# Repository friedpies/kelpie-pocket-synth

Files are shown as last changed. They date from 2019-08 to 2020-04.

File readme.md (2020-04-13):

## KELPIE - a polyphonic pocket synth

kelpie
---
### About

The KELPIE is a digital polyphonic synthesizer powered by the SGTL5000 audio DAC and an ARM Cortex M4 microcontroller. For a description of the full project, please visit the [Hackaday Project Page](https://hackaday.io/project/166460-kelpie-synth-module-for-keyboard-controllers)

---
### Repository Details

This repo houses all mechanical, electrical, and software files relating to the project, as well as graphical assets and other additional files.

- Mechanical CAD (mCAD) files can be found and viewed [here](https://a360.co/2Hpqyr5) via Fusion 360's online viewer. They can be downloaded directly in whatever format you need (including STLs for 3D printing). The link provided here directly reflects the most current progress and is kept up-to-date in real time.
- Electronics CAD ([Autodesk Eagle](https://www.autodesk.com/products/eagle/free-download)) files and schematics can be found [here](https://github.com/friedpies/kelpie-pocket-synth/tree/master/hardware/electronics). The parts library and full BOM can be exported from the schematic. This is the most up-to-date BOM.
- Firmware files, written in Arduino/C++ using [PlatformIO](https://platformio.org/) can be found [here](https://github.com/friedpies/kelpie-pocket-synth/tree/master/firmware)

### Audio Design

The synthesizer block diagram is shown below and was designed using the [Teensy Audio Design Tool](https://www.pjrc.com/teensy/gui/index.html)

BlockDiagram

---

### About the Device / How to Use


The KELPIE is a subtractive synthesizer that follows the standard 2 oscillator model. For those who have never used a subtractive synth before, there are plenty of resources online, I would recommend [this series of videos](https://www.youtube.com/watch?v=-1iK6drewCE) which do a great job of explaning and demonstrating the basics.

Some unique features of the KELPIE that are different and worth pointing out are:

 #### Oscillators
 - Each oscillator can only generate either a `pulse` waveform or `sawtooth` (both these waveforms are harmonically rich compared to triangle/sine waves, and can easily emulate other waves through filtering)
 - The `Pulse Width Modulation knob` (PWM) can only be heard if one (or both) of the waveforms are switched to a pulse waveform. This knob can be thought of as a "global" PWM
 - The `noise` knob is more of a noise "presence". At `0%`, oscillators 1 & 2 will dominate the output. Whereas at `100%`, the noise will completely dominate the output. At `50%` there will be an equal gain of Oscillators 1 & 2 and Noise.
 - `Coarse` refers to the relative tuning of Oscillator 2 to Oscillator 1. At `0%`, Oscillator 2 is tuned 1 octave below Oscillator 1, at `100%`, Oscillator 2 is tuned 1 octave above. Around `50%`, the knob is less sensitive in order to achieve less dramatic detuning.

#### Envelopes
  - The envelope knobs are responsible for both `amp` and `filter` envelopes. To switch between `amp` and `filter`, active the `shift` button. In future revisions, more features may be attached to the `shift` button.

#### Filter
  - Both filter `freq` and `Q` or (resonance) behave as expected in a traditional subtractive synthesizer. However, `depth` can be explained as the filter's impact or octave range. This effect is manifested in both the `LFO`'s `filter` parameter, as well as the `filter enevelope`'s effect on the overall sound.

#### LFO
  - The KELPIE has a single `LFO` or `low frequency oscillator` which is mapped to both the `filter`'s frequency as well as the overall `master gain`. The `rate` describes the frequency of oscillation, whereas the `filter` and `amp` parameters describe the `LFO`'s effect on those destinations.
  - Currently, the `LFO rate` is also mapped to the `modulation` MIDI CC message, so a player can easily adjust this parameter directly from their MIDI control interface.

#### GLIDE
  - This feature has not yet been implemented, but will allow the user to change the overall portamento rate (sliding between notes in `mono` mode)

#### MIDI CC
  - The KELPIE accepts `MIDI CC` messages from `102 - 119` which allow adjustment of all the parameters on the device. Both the built-in knobs and external MIDI knobs can be used simultaneously.

---

### Acknowledgements

I utilized and referenced a couple of open source libraries + repos for this project, as well as some very useful tools:

- PJRC Audio Library and Audio Design Tool
- [Bounce](https://github.com/thomasfredericks/Bounce2) library by Thomas Fredericks
- [MIDI](https://github.com/FortySevenEffects/arduino_midi_library) library by Francois Best
- thewknd's [Teensy Reference Boards schematics](https://github.com/thewknd/teensy-boards/tree/master/Teensy%203.2%20reference%20board%20clone)
- [Note's and Volts](https://www.notesandvolts.com/2018/05/teensy-synth-part-1.html) tutorial videos on building a Teensy synth

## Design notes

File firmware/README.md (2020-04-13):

### KELPIE SYNTHESIZER
By Kenneth Marut
www.kennethmarut.com

A custom hardware synthesizer based off of the Teensy 3.2 development hardware. This repository houses all firmware code, built using the Arduino language in PlatformIO.

## Getting Started with PlatformIO

This project uses VSCode with the PlatformIO extension instead of the Arduino IDE. To get set up, follow the instructions below:

- Download and install [VSCode](https://code.visualstudio.com/download) for your operating system
- Open VSCode and add the PlatformIO IDE Extension (platformio.platformio-ide)
- After PlatformIO finishes installing, restart VSCode
- Open PlatformIO by clicking on the "Alien" icon on VSCode's left toolbar
- Click on the "Platforms" icon, then search for the "Teensy" platform and install the latest version
- In the PIO Home window, select `Open Project` and navigate to `/kelpie-pocket-synth/firmware`
- Once the directory has been opened, click on the Alien PlatformIO icon on the left toolbar, and then select `Build` to compile the firmware
- Ensure the project has been successfully compiled, then connect your Kelpie/Teensy 3.2 via USB and select `Upload`
- After recompiling, the Teensy Loader should open and follow the familiar steps to flash the firmware to your device

The device firmware is written in C++ using the Arduino framework. The main entrypoint is `/src/main.cpp`. 
Custom libraries and classes can be found within the `/lib` directory. This is where most of the code lives.

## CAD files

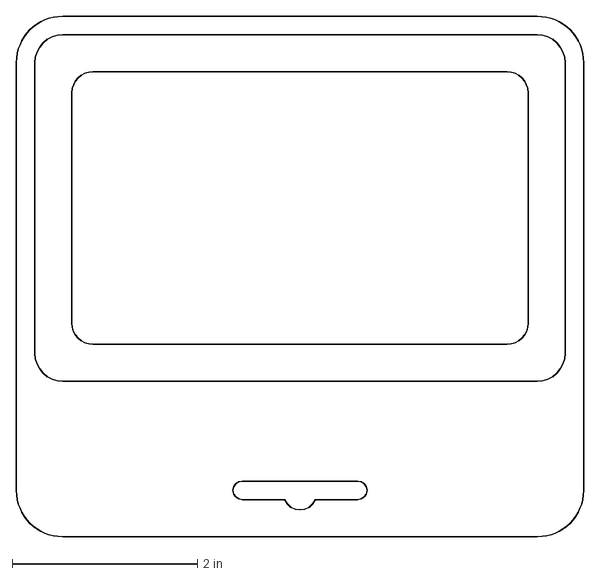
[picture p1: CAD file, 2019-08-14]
graphics/PACKAGING/OUTLINE.dxf
6.13 x 5.62 in

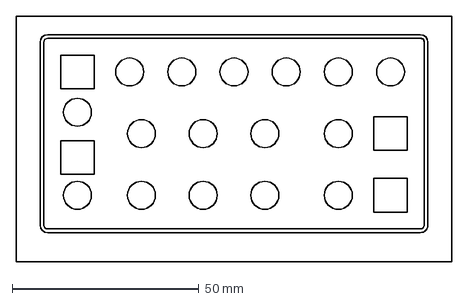
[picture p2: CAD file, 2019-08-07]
graphics/top_dxf.dxf
116.6 x 65.8 mm

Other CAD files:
hardware/enclosure/STLs/ENCLOSURE_TOP_TEXT_TEST.stl
hardware/enclosure/STLs/ENCLOSURE_BOTTOM.stl
hardware/enclosure/STLs/FDM-KNOB.stl
hardware/enclosure/STLs/KNOB.stl
hardware/enclosure/STLs/RING.stl
hardware/enclosure/STLs/KNOB_6MM.stl
hardware/enclosure/STLs/ENCLOSURE_TOP.stl

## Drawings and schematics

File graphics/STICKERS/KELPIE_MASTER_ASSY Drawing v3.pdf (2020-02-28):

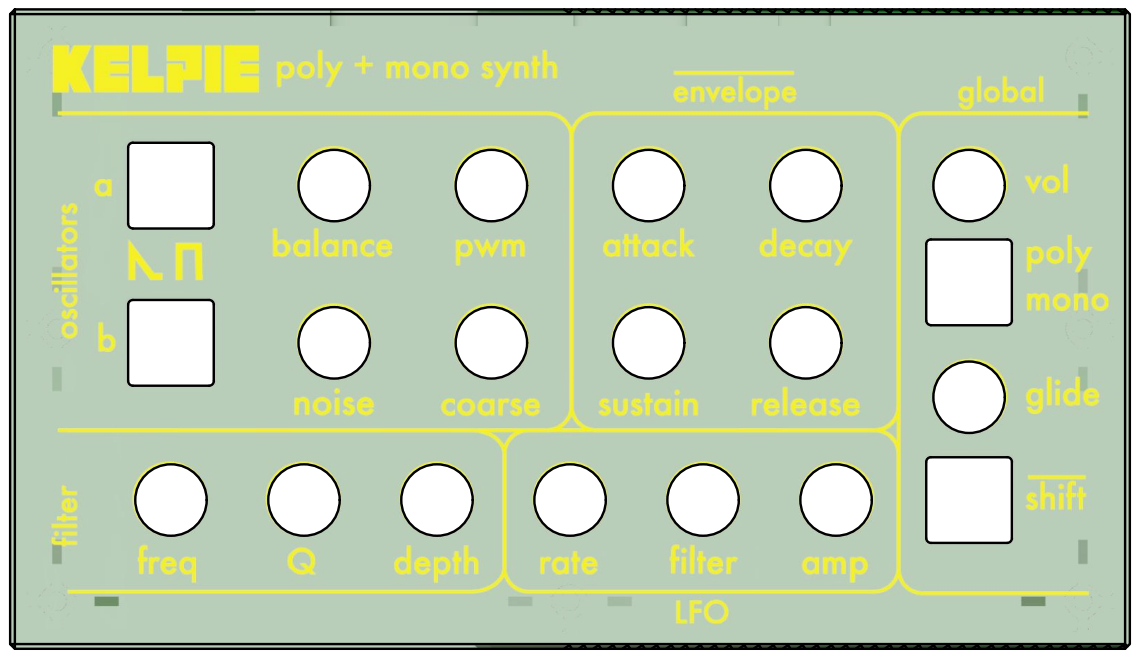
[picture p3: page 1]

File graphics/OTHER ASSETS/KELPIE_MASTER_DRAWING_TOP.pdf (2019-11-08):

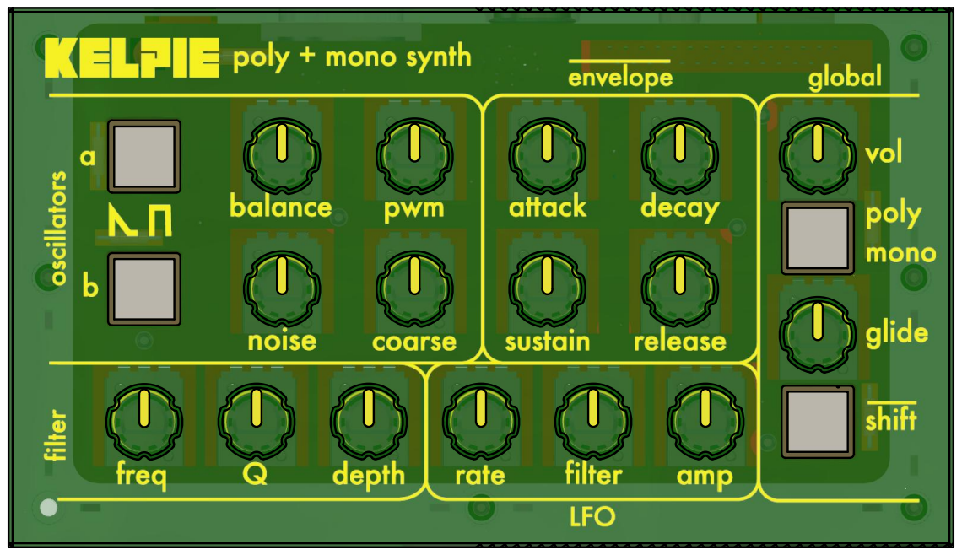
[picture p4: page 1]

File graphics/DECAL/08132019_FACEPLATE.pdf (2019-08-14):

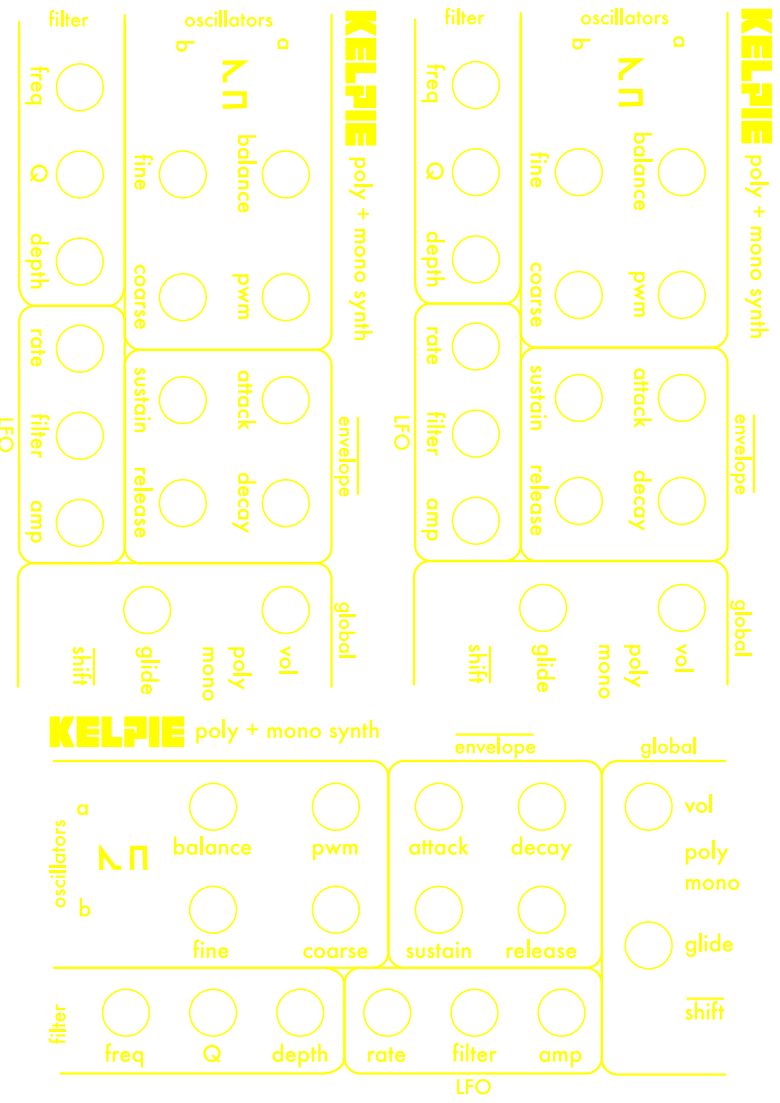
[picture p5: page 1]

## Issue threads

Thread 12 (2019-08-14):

feature: implement velocity sensitivity

friedpies, 2019-08-14:
- update synth engine to add amp to all voices

- map velocity to amp

friedpies, 2019-08-14:
Fixed!

Closed 2019-08-14.

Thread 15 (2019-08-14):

electronics: replace 30pin connector with ZIF connector

friedpies, 2019-08-14:
The current connector is expensive and impractical. Want to go with something cheaper and easier to install

Closed 2019-08-31.

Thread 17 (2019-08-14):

electronics: expose copper pads on potentiometer mounting holes

friedpies, 2019-08-14:
The mounting holes for the potentiometers are covered with silkscreen making it impossible to solder the mounting holes for the pots

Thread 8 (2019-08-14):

firmware: Implement Pitch Bend MIDI message

friedpies, 2019-08-14:
- Add a case for a midi pitch bend message
- adjust frequency when note is sounding in real time

friedpies, 2019-08-14:
DONE!

Closed 2019-08-14.

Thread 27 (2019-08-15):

firmware: device crashes when hitting 10-12 keys at once

friedpies, 2019-08-15:
seems to be a new issue

friedpies, 2019-08-19:
Temporary fix is to reduce number of voices to 6 at a time

Closed 2019-08-19.

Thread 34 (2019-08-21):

firmware: clear voices function

friedpies, 2019-08-21:
implement a function to clear all voices before switching from mono to poly, there is some residual data/noise that seems to carry over

Closed 2019-08-21.

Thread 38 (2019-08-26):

electronics: cut notch from upper PCB for MIDI connector

friedpies, 2019-08-26:
Wish I had thought of this earlier, likely can save a ton of space by moving some components around or notching out a chunk of the upper pcb to make space for MIDI connector... oh well

Closed 2019-08-31.

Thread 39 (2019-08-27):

electronics: replace all SMD components on upper PCB with thru hole

friedpies, 2019-08-27:
Figure that all pots and switches are thru-hole anyway, no reason to have two different types of components. This board is likely hand-assembled anyway.

friedpies, 2019-08-31:
Done

Closed 2019-08-31.

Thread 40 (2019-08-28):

hardware: fix ribs in lower enclosure

friedpies, 2019-08-28:
some ribs are interfering with lower half of enclosure

friedpies, 2019-08-31:
New design

Closed 2019-08-31.

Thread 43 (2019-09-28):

hardware: Possible incorrect component in Logic BOM

jawsper, 2019-09-28:
I saw in the BOM of the Logic board that you're referring to the AP7317-33SR voltage regulator for the SGTL5000 audio chip. I think this may be an error, since the audio chip needs a 1.1V - 2.0V level on that pin and this is a 3.3V regulator. The official Audio Shield uses the AP7317-18SR (package code SD) which does supply the correct level.

I hope this is only an error in the BOM, because it may very well break the audio chip.

friedpies, 2019-09-28:
hey @jawsper, I believe you are correct! Thank you for catching this error. I'll update the Eagle files and BOM. I really appreciate it. Also will swap those parts out on my boards. Luckily haven't broken anything yet!!

Closed 2019-09-28.

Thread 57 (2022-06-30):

The main repository's hardware PCB file is corrupted

denjhang, 2022-06-30:
I found a whole bunch of 1kb files, there must be something wrong.

berryelectronics, 2023-11-07:
had the same problem when downloading the repo as a zip, but works without a problem when using git clone

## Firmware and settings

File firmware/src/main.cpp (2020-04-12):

// MAIN CODE FOR KELPIE SYNTHESIZER
// WRITTEN BY KENNETH MARUT (WWW.KENNETHMARUT.COM)
// THIS PROJECT CAN BE FOLLOWED HERE: https://hackaday.io/project/166460-kelpie-synth-module-for-keyboard-controllers

#include <Arduino.h>
#include <MIDI.h>
#include <Audio.h>
#include <audioConnections.h>
#include <KelpieHelpers.h>
#include <KelpieIO.h>


elapsedMillis fps;
KelpieIO kelpieIO(true);
MIDI_CREATE_INSTANCE(HardwareSerial, Serial1, MIDI);

boolean prevButtonsState[4] = {false, false, false, false}; // initial state on boot
boolean *buttonsState;
byte changedKnobIndex;
byte changedButtonIndex;

SynthVoice VOICE_1 = {0, 0.0, 0, false, V1_A, V1_B, V1_N, V1_MIX, V1_AMP, V1_ENV, V1_FILT_ENV, V1_FILT};
SynthVoice VOICE_2 = {0, 0.0, 0, false, V2_A, V2_B, V2_N, V2_MIX, V2_AMP, V2_ENV, V2_FILT_ENV, V2_FILT};
SynthVoice VOICE_3 = {0, 0.0, 0, false, V3_A, V3_B, V3_N, V3_MIX, V3_AMP, V3_ENV, V3_FILT_ENV, V3_FILT};
SynthVoice VOICE_4 = {0, 0.0, 0, false, V4_A, V4_B, V4_N, V4_MIX, V4_AMP, V4_ENV, V4_FILT_ENV, V4_FILT};
SynthVoice VOICE_5 = {0, 0.0, 0, false, V5_A, V5_B, V5_N, V5_MIX, V5_AMP, V5_ENV, V5_FILT_ENV, V5_FILT};
SynthVoice VOICE_6 = {0, 0.0, 0, false, V6_A, V6_B, V6_N, V6_MIX, V6_AMP, V6_ENV, V6_FILT_ENV, V6_FILT};
SynthVoice VOICE_7 = {0, 0.0, 0, false, V7_A, V7_B, V7_N, V7_MIX, V7_AMP, V7_ENV, V7_FILT_ENV, V7_FILT};
SynthVoice VOICE_8 = {0, 0.0, 0, false, V8_A, V8_B, V8_N, V8_MIX, V8_AMP, V8_ENV, V8_FILT_ENV, V8_FILT};

const byte numPolyVoices = 8; // 
SynthVoice polyVoices[numPolyVoices] = {
    VOICE_1,
    VOICE_2,
    VOICE_3,
    VOICE_4,
    VOICE_5,
    VOICE_6,
    VOICE_7,
    VOICE_8};

const byte MONOBUFFERSIZE = 8; // how many voices we allow to be stored in the MONO buffer
byte monoBuffer[MONOBUFFERSIZE];

SynthState globalState = {
    // default synth state on startup
    WAVEFORM_SAWTOOTH, // WAVEFORM1
    WAVEFORM_SAWTOOTH, // WAVEFORM2
    false,             // IS_POLY
    false,             // shift
    1.0,               // OSC1_VOL
    1.0,               // OSC2_VOL
    1.0,               // NOISE_VOL
    0.0,               // OSC_CONSTANT
    0.5,               // PWM
    1.0,               // DETUNE
    1.0,               // PITCH_BEND
    0.0,               // LFO_FREQ
    0.0,               // LFO_FILTER_GAIN
    0.0,               // LFO_AMP_GAIN
    0.0,               // AMP_ATTACK
    0.0,               // AMP_DECAY
    1.0,               // AMP_SUSTAIN
    500,               // AMP_RELEASE ms
    0.0,               // FILTER_ATTACK
    0.0,               // FILTER_DECAY
    1.0,               // FILTER_SUSTAIN
    500,               // FILTER_RELEASE
    10000,             // FILTER_FREQ
    1.1,               // FILTER_Q
    1.0,               // FILTER_OCTAVE
    0.5,               // MASTER_VOL
    1.0,               // POLY_GAIN_MULTIPLIER
    0.9,               // PREFILTER_GAIN
    0,                 // PREV_NOTE
    0                  // CURRENT NOTE
};

void handleMidiEvent(byte channelByte, byte controlByte, byte valueByte)
{
  byte messageType = MIDI.getType();
  byte note = MIDI.getData1();
  byte velocity = MIDI.getData2();
  int pitch = 0; // initialize to zero, only applies in pitch bend case
  float pitchBend = 0.00;
  switch (messageType)
  {
  case midi::NoteOn:
    kelpieIO.blinkMidiLED(true);
    if (note > 23 && note < 108)
    {
      LFO.phase(0); // retrigger LFO on keypress
      float noteGain = pow(float(velocity) * DIV127, VELOCITY_CURVE);

      if (globalState.IS_POLY == true) // depending on mode send to buffer
      {
        keyBuffPoly(note, noteGain, true);
      }
      else
      {
        keyBuffMono(note, noteGain, true);
      }
    }
    break;

  case midi::NoteOff:
    kelpieIO.blinkMidiLED(false);
    if (note > 23 && note < 108)
    {
      if (globalState.IS_POLY == true) // depending on mode send to buffer
      {
        keyBuffPoly(note, velocity, false);
      }
      else
      {
        keyBuffMono(note, velocity, false);
      }
    }
    break;

  case midi::PitchBend:
    pitch = velocity * 256 + note; // this converts 8 bit values into a 16 bit value for precise pitch control
    pitchBend = map(double(pitch), 0, 32767, -2, 2);
    globalState.PITCH_BEND = pow(2, pitchBend / 12);
    for (byte i = 0; i < numPolyVoices; i++)
    {
      float currentFreq = polyVoices[i].noteFreq;
      polyVoices[i].waveformA.frequency(currentFreq * globalState.PITCH_BEND);
      polyVoices[i].waveformB.frequency(currentFreq * globalState.PITCH_BEND * globalState.DETUNE);
    }
    break;

  case midi::ControlChange:
    byte ccNum = note; // redefining for clarity
    byte value = velocity;
    float normalizedKnobVal = (value * DIV127);
    switch (ccNum) {
      case 1: // MODULATION WHEEL
        globalState.LFO_FREQ = normalizedKnobVal * LFO_FREQ_MAX;
        LFO.frequency(globalState.LFO_FREQ);
      break;
      case 5: // GLIDE
      break;
      case 7: // MASTER VOLUME
        globalState.MASTER_VOL = normalizedKnobVal * MAX_MASTER_GAIN;
        MASTER_GAIN.gain(globalState.MASTER_VOL * globalState.POLY_GAIN_MULTIPLIER);
      break;
      case 8: // OSC BALANCE
        globalState.OSC1_VOL = normalizedKnobVal;
        globalState.OSC2_VOL = 1 - (normalizedKnobVal);
        globalState.OSC_CONSTANT = calculateOscConstant(globalState.OSC1_VOL, globalState.OSC2_VOL, globalState.NOISE_VOL);
        setWaveformLevels(globalState.OSC1_VOL, globalState.OSC2_VOL, globalState.NOISE_VOL, globalState.OSC_CONSTANT);
      break;
      case 102: // OSCILLATOR PWM
        globalState.PWM = 0.1 + 0.4 * (1 - normalizedKnobVal);
        for (byte i = 0; i < numPolyVoices; i++)
        {
          polyVoices[i].waveformA.pulseWidth(globalState.PWM);
          polyVoices[i].waveformB.pulseWidth(globalState.PWM);
        }
      break;
      case 103: // NOISE VOLUME
        globalState.NOISE_VOL = normalizedKnobVal;
        globalState.OSC_CONSTANT = calculateOscConstant(globalState.OSC1_VOL, globalState.OSC2_VOL, globalState.NOISE_VOL);
        setWaveformLevels(globalState.OSC1_VOL, globalState.OSC2_VOL, globalState.NOISE_VOL, globalState.OSC_CONSTANT);
      break;
      case 104: // OSC DETUNE
        globalState.DETUNE = calculateDetuneValue(normalizedKnobVal);
        for (byte i = 0; i < numPolyVoices; i++)
        {
          polyVoices[i].waveformB.frequency(polyVoices[i].noteFreq * globalState.DETUNE * globalState.PITCH_BEND);
        }
      break;
      case 105: // FILTER FREQUENCY
        globalState.FILTER_FREQ = FILTER_CUTOFF_MAX * pow(normalizedKnobVal, 3);
        for (byte i = 0; i < numPolyVoices; i++)
        {
          polyVoices[i].filter.frequency(globalState.FILTER_FREQ);
        }
      break;
      case 106: // FILTER RESONANCE
        globalState.FILTER_Q = (FILTER_Q_MAX * normalizedKnobVal) + 1.1;
        globalState.PREFILTER_GAIN = 1 / globalState.FILTER_Q;
        for (byte i = 0; i < numPolyVoices; i++)
        {
          polyVoices[i].filter.resonance(globalState.FILTER_Q);
        }
      break;
      case 107: // FILTER DEPTH
        globalState.FILTER_OCTAVE = FILTER_OCTAVE_DEPTH * normalizedKnobVal;
        for (byte i = 0; i < numPolyVoices; i++)
        {
          polyVoices[i].filter.octaveControl(globalState.FILTER_OCTAVE);
        }
      break;
      case 108: // LFO RATE
        globalState.LFO_FREQ = LFO_FREQ_MAX * pow(normalizedKnobVal, 5);
        LFO.frequency(globalState.LFO_FREQ);
      break;
      case 109: // LFO DESTINATION FILTER
        globalState.LFO_FILTER_GAIN = (normalizedKnobVal);
        LFO_MIXER_FILTER.gain(1, globalState.LFO_FILTER_GAIN);
      break;
      case 110: // LFO DESTINATION AMP
        globalState.LFO_AMP_GAIN = (normalizedKnobVal);
        LFO_MIXER_AMP.gain(1, globalState.LFO_AMP_GAIN);
      break;
      case 111: // AMP ATTACK
      globalState.AMP_ATTACK = AMP_ATTACK_MAX * (normalizedKnobVal);
      if (globalState.AMP_ATTACK < 15) //
      {
        globalState.AMP_ATTACK = 0;
      }
      for (byte i = 0; i < numPolyVoices; i++)
      {
        polyVoices[i].ampEnv.attack(globalState.AMP_ATTACK);
      }
      break;
      case 112: // AMP DECAY
        globalState.AMP_DECAY = AMP_DECAY_MAX * normalizedKnobVal;
        for (byte i = 0; i < numPolyVoices; i++)
        {
          polyVoices[i].ampEnv.decay(globalState.AMP_DECAY);
        }
      break;
      case 113: // AMP SUSTAIN
        globalState.AMP_SUSTAIN = normalizedKnobVal;
        for (byte i = 0; i < numPolyVoices; i++)
        {
          polyVoices[i].ampEnv.sustain(globalState.AMP_SUSTAIN);
        }
      break;
      case 114: // AMP RELEASE
        globalState.AMP_RELEASE = AMP_RELEASE_MAX * normalizedKnobVal;
        for (byte i = 0; i < numPolyVoices; i++)
        {
          polyVoices[i].ampEnv.release(globalState.AMP_RELEASE);
        }
      break;
      case 115: // FILTER ATTACK
            globalState.FILTER_ATTACK = FILTER_ATTACK_MAX * normalizedKnobVal;
      if (globalState.FILTER_ATTACK < 15) //
      {
        globalState.FILTER_ATTACK = 0;
      }
      for (byte i = 0; i < numPolyVoices; i++)
      {
        polyVoices[i].filterEnv.attack(globalState.FILTER_ATTACK);
      }
      break;
      case 116: // FILTER DECAY
        globalState.FILTER_DECAY = FILTER_DECAY_MAX * normalizedKnobVal;
        for (byte i = 0; i < numPolyVoices; i++)
        {
          polyVoices[i].filterEnv.decay(globalState.FILTER_DECAY);
        }
      break;
      case 117: // FILTER SUSTAIN
        globalState.FILTER_SUSTAIN = normalizedKnobVal;
        for (byte i = 0; i < numPolyVoices; i++)
        {
          polyVoices[i].filterEnv.sustain(globalState.FILTER_SUSTAIN);
        }
      break;
      case 118: // FILTER RELEASE
        globalState.FILTER_RELEASE = FILTER_RELEASE_MAX * normalizedKnobVal;
        for (byte i = 0; i < numPolyVoices; i++)
        {
          polyVoices[i].filterEnv.release(globalState.FILTER_RELEASE);
        }
      break;
    }
    break;
  }
}

void setup()
{
  MIDI.begin();
  AudioMemory(80);
  sgtl5000_1.enable();
  sgtl5000_1.volume(globalState.MASTER_VOL);

  AudioNoInterrupts();
  for (byte i = 0; i < numPolyVoices; i++)
  {
    polyVoices[i].waveformA.begin(globalState.WAVEFORM1);
    polyVoices[i].waveformA.amplitude(0.33);
    polyVoices[i].waveformA.frequency(82.41);
    polyVoices[i].waveformA.pulseWidth(0.15);

    polyVoices[i].waveformB.begin(globalState.WAVEFORM2);
    polyVoices[i].waveformB.amplitude(0.33);
    polyVoices[i].waveformB.frequency(82.41);
    polyVoices[i].waveformB.pulseWidth(0.15);

    polyVoices[i].noise.amplitude(0.33);

    polyVoices[i].waveformMixer.gain(0, 1.0);
    polyVoices[i].waveformMixer.gain(1, 1.0);
    polyVoices[i].waveformMixer.gain(2, 1.0);

    polyVoices[i].waveformAmplifier.gain(0.0);

    polyVoices[i].ampEnv.attack(globalState.AMP_ATTACK);
    polyVoices[i].ampEnv.decay(globalState.AMP_DECAY);
    polyVoices[i].ampEnv.sustain(globalState.AMP_SUSTAIN);
    polyVoices[i].ampEnv.release(globalState.AMP_RELEASE);

    polyVoices[i].filter.frequency(globalState.FILTER_FREQ);
    polyVoices[i].filter.resonance(globalState.FILTER_Q);
    polyVoices[i].filter.octaveControl(2.0);
  }
  AudioInterrupts();

  DC_OFFSET.amplitude(1.0);
  LFO.amplitude(1.0);
  LFO.frequency(2.0);
  LFO.phase(90);

  LFO_MIXER_FILTER.gain(0, 1); // THIS IS THE AMP THAT ADJUSTS HOW MUCH OF THE LFO IS FED INTO THE FILTER
  LFO_MIXER_FILTER.gain(1, 0);

  for (byte i = 0; i < 4; i++)
  {
    V14_MIX.gain(i, 0.25);
    V58_MIX.gain(i, 0.25);
  }

  ALL_VOICE_MIX.gain(0, 0.5);
  ALL_VOICE_MIX.gain(1, 0.5);

  // READ AND INITIALIZE ALL KNOBS
  for (byte knobIndex = 0; knobIndex < 16; knobIndex++)
  {
    kelpieIO.setKnobOnStartup(knobIndex);
    handleKnobChange(kelpieIO.getKnob(knobIndex));
  }
  kelpieIO.bootupAnimation();
}

void loop()
{
  if (MIDI.read())
  {
    byte channel = MIDI.getChannel();
    byte controlType = MIDI.getData1();
    byte value = MIDI.getData2();
    handleMidiEvent(channel, controlType, value);
  }

  changedKnobIndex = kelpieIO.getIndexOfChangedKnob();
  if (changedKnobIndex > -1)
  {
    handleKnobChange(kelpieIO.getKnob(changedKnobIndex));
  }

  changedButtonIndex = kelpieIO.getIndexOfChangedButton();
  if (changedButtonIndex > -1)
  {
    handleButtonPress(kelpieIO.getButton(changedButtonIndex));
  }

  if (fps > 24)
  {
    if (PEAK.available())
    {
      fps = 0;
      int monoPeak = PEAK.read() * 100.0;
      Serial.print("|");
      for (int cnt = 0; cnt < 100; cnt++)
      if (cnt < monoPeak)
      {
        Serial.print(">");
      } else if (cnt >= monoPeak && cnt < 99)
      {
        Serial.print(" ");
      } else if (cnt > 99)
      {
        Serial.println("|");
      }
      Serial.print(monoPeak);
      Serial.println();
    }
  }
}

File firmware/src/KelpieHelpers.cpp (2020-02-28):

#include <KelpieHelpers.h>

void activateVoice(byte index, byte note, float frequency, float gain)
{
  polyVoices[index].note = note;
  polyVoices[index].noteFreq = frequency;
  polyVoices[index].waveformA.frequency(frequency * globalState.PITCH_BEND);
  polyVoices[index].waveformA.phase(0);
  polyVoices[index].waveformB.frequency(frequency * globalState.PITCH_BEND * globalState.DETUNE);
  polyVoices[index].waveformB.phase(0);
  polyVoices[index].waveformAmplifier.gain(gain * globalState.PREFILTER_GAIN);
  polyVoices[index].ampEnv.noteOn();
  polyVoices[index].filterEnv.noteOn();
}

void deactivateVoice(byte index)
{
  polyVoices[index].ampEnv.noteOff();
  polyVoices[index].filterEnv.noteOff();
  polyVoices[index].note = -1;
}

void playNoteMono(byte playMode, byte note, float noteGain)
{
  globalState.PREV_NOTE = globalState.CURRENT_NOTE;
  globalState.CURRENT_NOTE = note;
  if (globalState.CURRENT_NOTE == globalState.PREV_NOTE) {
    globalState.PREV_NOTE = 0; // this is a quick fix
    globalState.CURRENT_NOTE = 0;
  }
  float baseNoteFreq = noteFreqs[note];
  AudioNoInterrupts();
  switch (playMode) 
  {
  case PLAY_NOTE: // PLAYNOTE
    for (byte i = 0; i < numPolyVoices; i++)
    {
      activateVoice(i, note, baseNoteFreq, noteGain);
    }
    break;
  case UPDATE_NOTE: // UPDATE NOTE
    for (byte i = 0; i < numPolyVoices; i++)
    {
      polyVoices[i].note = note;
      polyVoices[i].noteFreq = baseNoteFreq;
      polyVoices[i].waveformA.frequency(baseNoteFreq);// * globalState.PITCH_BEND);
      polyVoices[i].waveformB.frequency(baseNoteFreq * globalState.PITCH_BEND * globalState.DETUNE);
    }
    break;
  case STOP_NOTE: // STOP NOTE
    for (byte i = 0; i < numPolyVoices; i++)
    {
      deactivateVoice(i);
    }
    break;
  }
  AudioInterrupts();
};

void bufferShift(byte indexToRemove, byte currentSizeOfBuffer)
{
  for (byte i = indexToRemove + 1; i < currentSizeOfBuffer; i++)
  {
    monoBuffer[i - 1] = monoBuffer[i];
  }
  monoBuffer[currentSizeOfBuffer - 1] = 0;
}

void keyBuffMono(byte note, float noteGain, boolean playNote)
{
  static byte currentNote = 0; // this might make more sense to start with -1 to keep indexing legible
  if (playNote)
  {
    if (currentNote == MONOBUFFERSIZE) // if we exceed buffer size, newest note goes on end, remove first note and SHIFT all notes down 1
    {
      bufferShift(0, currentNote);
      currentNote = MONOBUFFERSIZE - 1;
    }
    monoBuffer[currentNote] = note;
    playNoteMono(PLAY_NOTE, note, noteGain);
    currentNote++;
  }
  else // key is released
  {
    byte foundNoteIndex = MONOBUFFERSIZE; // default to index larger than buffer size
    for (byte i = 0; i <= (currentNote); i++)
    {

      if (note == monoBuffer[i])
      {
        foundNoteIndex = i;
        monoBuffer[i] = 0;
        // note has to be stopped
        bufferShift(foundNoteIndex, currentNote);
        currentNote--;
        if (currentNote == 0)
        {
          playNoteMono(STOP_NOTE, note, noteGain); 
        } else {
          playNoteMono(UPDATE_NOTE, monoBuffer[currentNote - 1], noteGain); // this is causing issues with the RELEASE phase of the AMP ENV
        }
      }
    }
  }
}

void keyBuffPoly(byte note, float noteGain, boolean playNote)
{
  if (playNote) // on keypress
  {
    float baseNoteFreq = noteFreqs[note];
    for (byte i = 0; i < numPolyVoices; i++)
    {
      if (polyVoices[i].ampEnv.isActive() == false)
      {
        activateVoice(i, note, baseNoteFreq, noteGain);
        break;
      }
    }
  }
  else // key released
  {
    for (byte i = 0; i < numPolyVoices; i++)
    {
      if (polyVoices[i].note == note)
      {
        deactivateVoice(i);
      }
    }
  }
}

void handleButtonPress(boolean *buttonsState)
{
  for (byte i = 0; i < 4; i++)
  {
    if (buttonsState[i] != prevButtonsState[i]) // which button changed?
    {
      prevButtonsState[i] = buttonsState[i];
      int pressedButton = i;
      boolean buttonState = boolean(buttonsState[i]);
      switch (pressedButton)
      {
      case OSC_1_BUTTON: // button 1 was pressed, toggle between waveforms
        if (buttonState == true)
        {
          globalState.WAVEFORM1 = WAVEFORM_PULSE;
        }
        else
        {
          globalState.WAVEFORM1 = WAVEFORM_SAWTOOTH;
        }
        for (byte i = 0; i < numPolyVoices; i++)
        {
          polyVoices[i].waveformA.begin(globalState.WAVEFORM1);
        }
        break;

      case OSC_2_BUTTON:
        if (buttonState == true)
        {
          globalState.WAVEFORM2 = WAVEFORM_PULSE;
        }
        else
        {
          globalState.WAVEFORM2 = WAVEFORM_SAWTOOTH;
        }
        for (byte i = 0; i < numPolyVoices; i++)
        {
          polyVoices[i].waveformB.begin(globalState.WAVEFORM2);
        }
        break;

      case POLY_MONO_BUTTON:
      // wipe out all notes playing just in case
        for (byte i = 0; i < numPolyVoices; i++) {
          deactivateVoice(i);
        }
        if (buttonState == true)
        {
          globalState.IS_POLY = true;
          globalState.POLY_GAIN_MULTIPLIER = POLY_MULTIPLIER;

        }
        else
        {
          globalState.IS_POLY = false;
          globalState.POLY_GAIN_MULTIPLIER = 1.0;
        }
        MASTER_GAIN.gain(globalState.MASTER_VOL * globalState.POLY_GAIN_MULTIPLIER);
        break;

      case SHIFT_BUTTON:

        if (buttonState == true)
        {
          globalState.SHIFT = true;
        }
        else
        {
          globalState.SHIFT = false;
        }
        break;

      default:
        break;
      }
    }
  }
}
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

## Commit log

2019-06-03 Boilerplate setup
    Initialized repo with simple "Hello World" program, tested MK20 on Kelpie board, working
2019-06-19 test pins and write pin defines
2019-06-20 test input switches, working
2019-06-28 restructuring folders
    [CONTROL.csv, MCU.csv, control.xlsx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]
2019-07-22 add digital read for buttons
2019-07-22 debouce pushbuttons and light corresponding LEDs
2019-08-04 rewrte buttons struct to match knobs
2019-08-05 implement env and filter
2019-08-05 implemented filter
2019-08-06 a couple quick fixes
    [main.cpp]
2019-08-07 add dxf
    [top_dxf.dxf]
2019-08-07 added filter envs to every voice
2019-08-13 quick fixes on gain and clipping
    [KelpieHelpers.cpp, main.cpp]
2019-08-14 pushing graphics
    [OUTLINE.dxf]
2019-08-14 implemented velocity sensitivity for poly synth
2019-08-14 added case for retrieving pitch bend control change and convert to 16 bit val
2019-08-14 implemented pitch bend
2019-08-15 broken: device crashes when 7 notes played simultaneously
    [KelpieHelpers.cpp, main.cpp]
2019-08-16 broken: removing voices until crashing stops
    [Kelpie.cpp, KelpieHelpers.cpp, main.cpp]
2019-08-20 mono working, need to replace all monovoices with polyvoices for consistency
    [KelpieHelpers.cpp]
2019-08-21 electronics updates
    [KELPIE_LOGIC_BOM.csv, KELPIE_LOGIC_BOM.xlsx, KELPIE_LOGIC_BOM_SEEED.xlsx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]
2019-08-22 update hardware files
    [CONTROL.csv, KELPIE_ENCLOSURE_BOTTOM.stl, KELPIE_ENCLOSURE_TOP.stl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]
2019-08-27 fixed a small bug in eagle brd file due to merge conflict
    [KELPIE_LOGIC_PCB.brd]
2019-08-27 updated potentiometer mounting holes
2019-08-27 changed resistors on upper PCB to thru hole, still need to do LED
2019-08-29 upper PCB revisions
    [KELPIE_INPUT_PCB.brd]
2019-08-29 added ribbon connector on lower board
    [KELPIE_INPUT_PCB.brd]
2019-08-29 before export eCAM files
    [KELPIE_LOGIC_PCB.brd]
2019-08-30 board rev 2 done, sent to seeed for manufacture
    [KELPIE_INPUT_PCB.brd, KELPIE_INPUT_PCB.sch, KELPIE_LOGIC_PCB.brd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]
2019-09-04 working on bom
    [KELPIE_INPUT_PCB.brd, KELPIE_INPUT_PCB.csv, KELPIE_INPUT_PCB.sch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]
2019-09-12 turn on midi led for prototype 2
2019-09-28 hardware fix, updated AP7313 regulator from 3.3V to 1.8V reg, thanks @jawsper for catching this
    [KELPIE_LOGIC_PCB.brd, KELPIE_LOGIC_PCB.sch]
2019-09-28 hotfix, reexported BOM in BOM folder
    [KELPIE_INPUT_PCB.brd, KELPIE_INPUT_PCB.csv, KELPIE_LOGIC_PCB.brd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]
2019-11-02 changed filter knob response, removed lookup table (it was dumb)
2019-11-02 fixed some resonance clipping attentuation
    [KelpieHelpers.cpp, main.cpp]
2019-11-03 fixed mono buffer not clearing
    [KelpieHelpers.cpp, main.cpp]
2019-11-13 Fixed envelope issue on release (#54)
    * adding synthstate class
    * uploading graphics
    * working on new class, fixed buffer bug
    [KelpieHelpers.cpp, main.cpp]
2019-11-15 getting prev and current note
2019-12-30 Bug fixes - Added peak analyzer, reduced clipping - Fixed note carry issue - Fixed velocity curves
    [KelpieHelpers.cpp, main.cpp]
2020-02-25 STLs for FDM
    [ENCLOSURE_BOTTOM.stl, ENCLOSURE_TOP.stl, ENCLOSURE_TOP_TEXT_TEST.stl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]
2020-04-12 refactored button struct to match new pot struct
2020-10-17 more lfs files
    [ENCLOSURE_BOTTOM.stl, ENCLOSURE_TOP.stl, ENCLOSURE_TOP_TEXT_TEST.stl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]
